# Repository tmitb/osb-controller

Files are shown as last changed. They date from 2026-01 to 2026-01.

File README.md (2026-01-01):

# OSB Controller

This branch contains a project that includes both hardware and software stacks for a gamepad based on the ESP32‑C3. The project was started out of a personal need for a button pad to control OBS while playing games.

The information and experience gathered from this project will be used for the following potential projects:
- Racing sim wheel
- Racing sim button stack
- Flight‑sim controls

## Hardware
I chose the ESP32‑C3 because I have a lot of them lying around. The goal is to build a fully functional Bluetooth gamepad.

### Design considerations
- The development board I have is the ESP32‑C3 Super Mini. Due to its size it only has 11 GPIO pins that can be used safely after removing two buttons (the Boot button and the LED). Eleven buttons will be more than enough for the initial version that controls OBS.
- The shell will be 3D‑printed.
- Mechanical keyboard switches will be used for the buttons.

### BOM
- [x] ESP32‑C3 Super Mini
- [x] Shell
- [x] Switches
- [x] Keycaps

#### ESP32‑C3 Gamepad
Although it is possible to have 11 buttons, I opted to use only 10 of them because that looks better. It may be possible to add more buttons, as there are additional GPIOs (GPIO8 and GPIO9) that are wired for other functions – the built‑in LED and the BOOT pin, respectively.

Ultimately, I have used GPIO0‑7, 10, and 20 for buttons 1‑10.

#### 3D prints
STL files can be found in the `hardware/3d-models` directory.

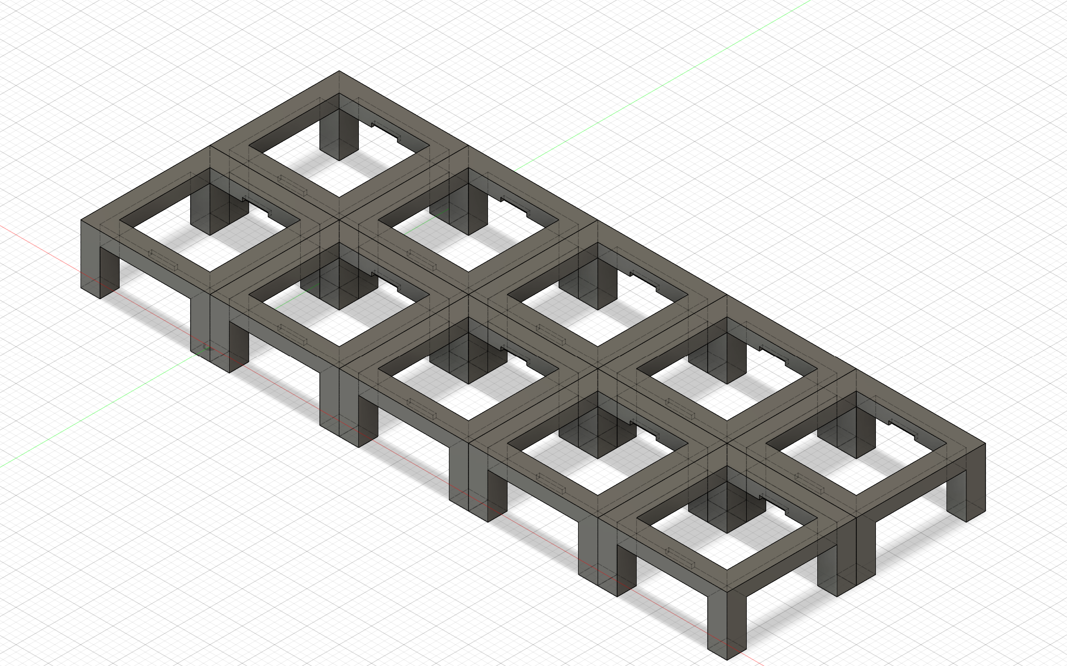
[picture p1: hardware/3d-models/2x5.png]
Button Grid

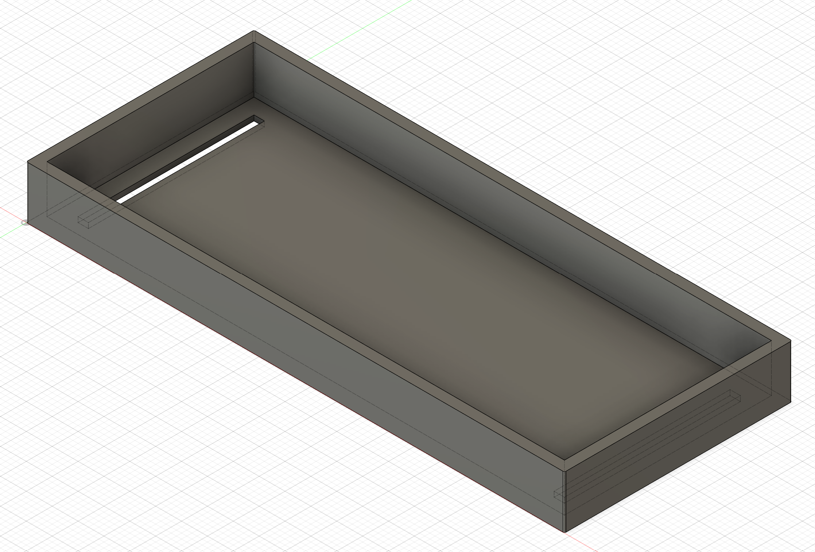
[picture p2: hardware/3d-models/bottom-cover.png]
Bottom Cover

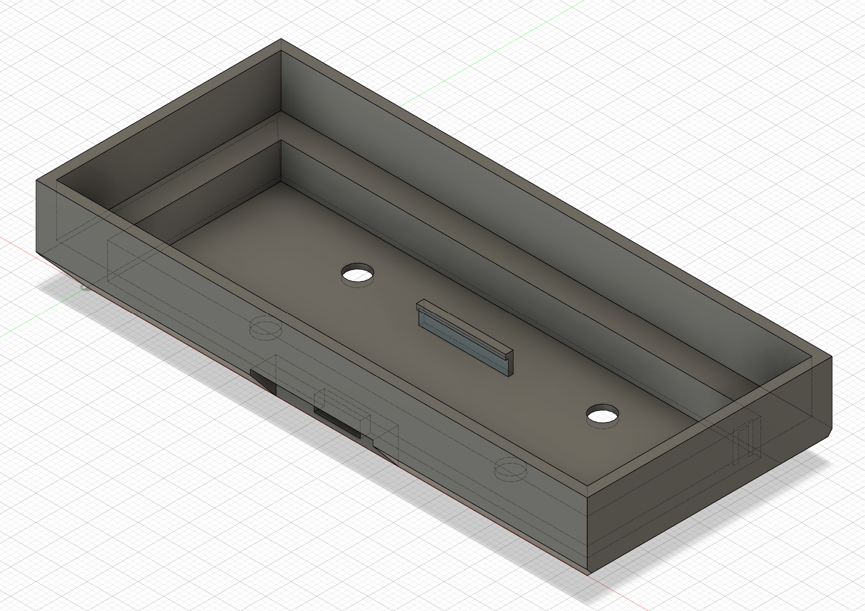
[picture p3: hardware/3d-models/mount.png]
Mount

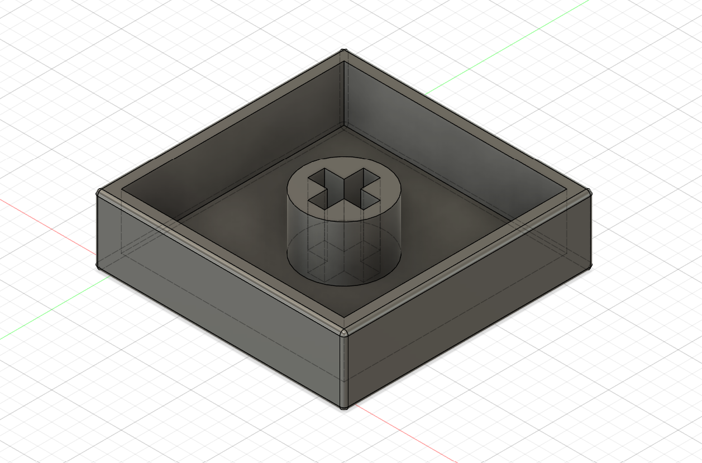
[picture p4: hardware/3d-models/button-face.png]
Button face


#### Assembly
I aimed to design a shell that is easy to assemble and disassemble because prototype devices typically require many iterations.

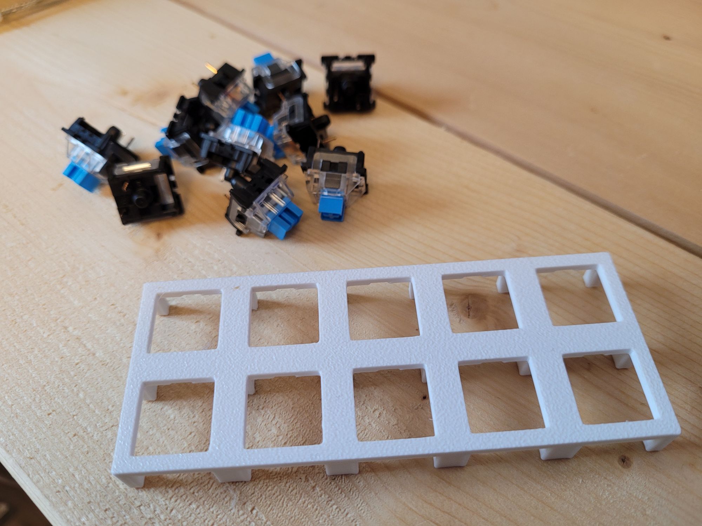
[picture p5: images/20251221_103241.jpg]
Base and switches

The first step was to create a grid that the switches could easily snap into. The dimensions are based on Cherry‑style switches with notches on the top and bottom sides to ensure a tight fit.

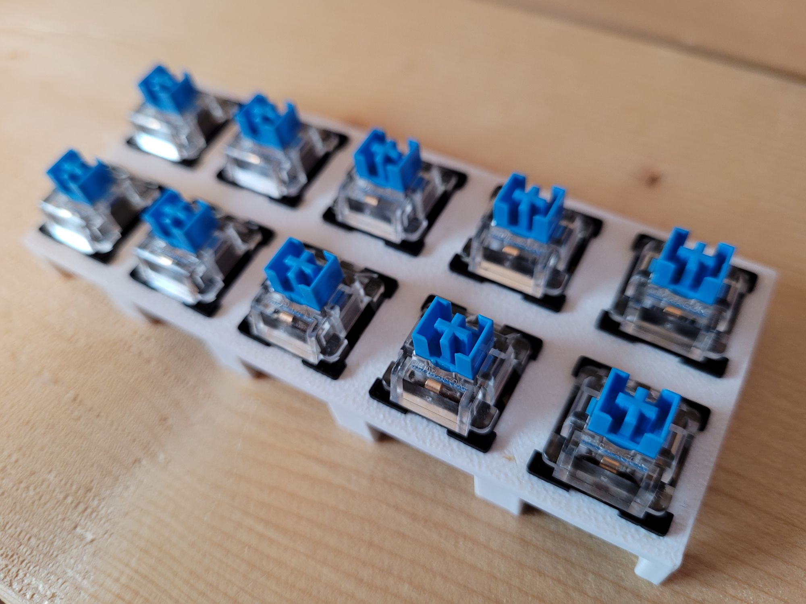
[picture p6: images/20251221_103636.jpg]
Switches in the grid

This is how it looks after all the buttons are installed.
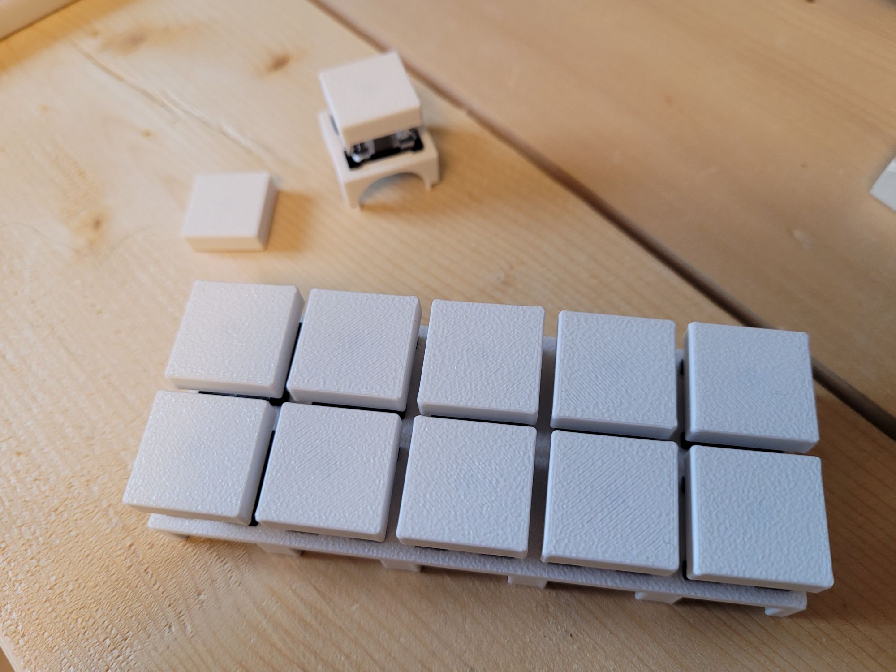
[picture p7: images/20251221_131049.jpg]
Button caps installed

The button caps are flat; this is not a keyboard, so the slight concave shape common on keyboards is unnecessary.

I found that the switches have noticeable slack when I wiggle them. They were likely low‑quality units purchased cheaply from AliExpress – I don’t remember the exact model. They look aligned enough for me, but others may find this unacceptable.

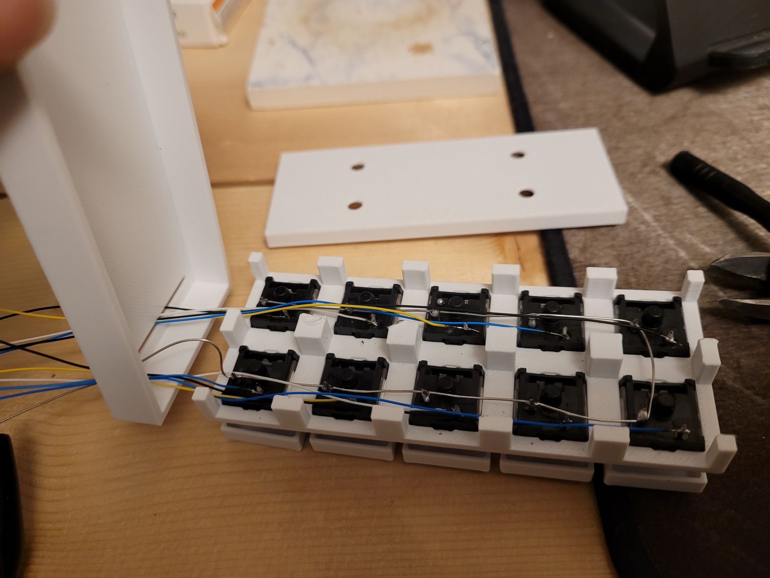
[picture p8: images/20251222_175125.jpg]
Buttons soldered


For Rev 1 I decided to solder all the buttons. Eventually I would like to design a PCB for it, but that is a future task.
If you look closely, there are two slots on the bottom cover for routing wires. Originally I added snap‑fit tabs on the mount to hold pieces together, but they were not strong enough for repeated assembly/disassembly cycles. After about ten failed prototypes I gave up on the idea of having tabs to hold the pieces together, which left me with two slots design instead of necessary single slot.

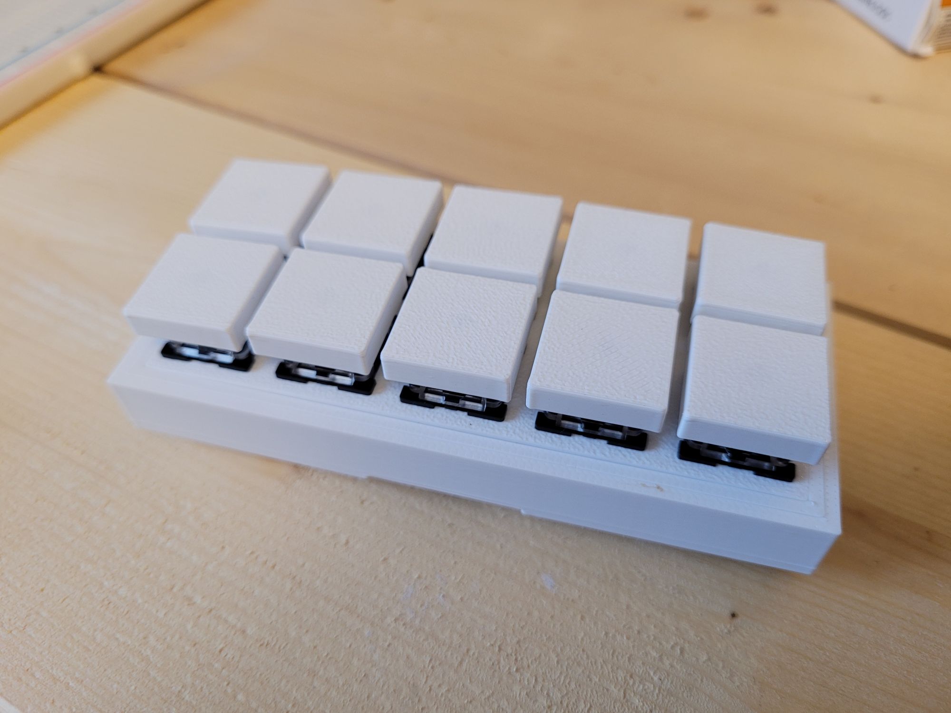
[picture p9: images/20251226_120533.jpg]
Fully Assembled

It is very easy to assemble this device: place the grid into the cover, then insert the whole cover‑plus‑grid assembly into the mount. The natural layer lines of the 3D prints create enough friction to hold the assembly tightly. One unexpected outcome is that disassembly can be quite hard because the friction is high; I could pry it apart with sufficient force, but I was not inclined to print another shell after more than ten failed prototypes to fix a minor inconvinence.

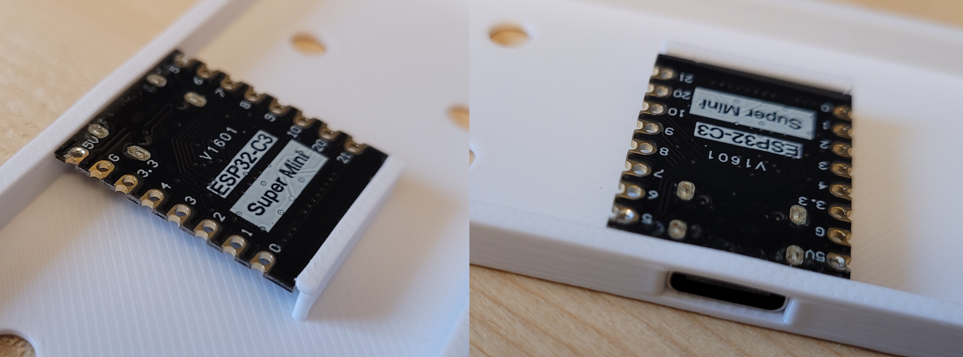
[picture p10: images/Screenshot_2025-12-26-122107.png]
ESP32‑C3 mounted

I was unable to photograph how the ESP32‑C3 Super Mini is mounted, so I used a photo of a failed prototype instead – the mounting concept is identical. When looking at the module, the USB port protrudes slightly from the PCB. Using this, I created a slot in the side of the mount to push the port into, and at an exact distance I added a wall with a slight tab at the top. Because PLA prints have enough flex, I could jam the module in with a bit of force. It fits tightly without issues so far, though stress over time may become a concern.

#### Arduino code
A single sketch for the ESP32‑C3 can be found [here](hardware/ble-gamepad/ble-gamepad.ino). The code is a slightly modified version of an example from the [NimBLE‑Arduino](https://github.com/h2zero/NimBLE-Arduino) library.

#### Simple tests
Even without a full software stack to use it as an OBS controller, this works as a perfectly good game controller. First, pair it via Bluetooth.

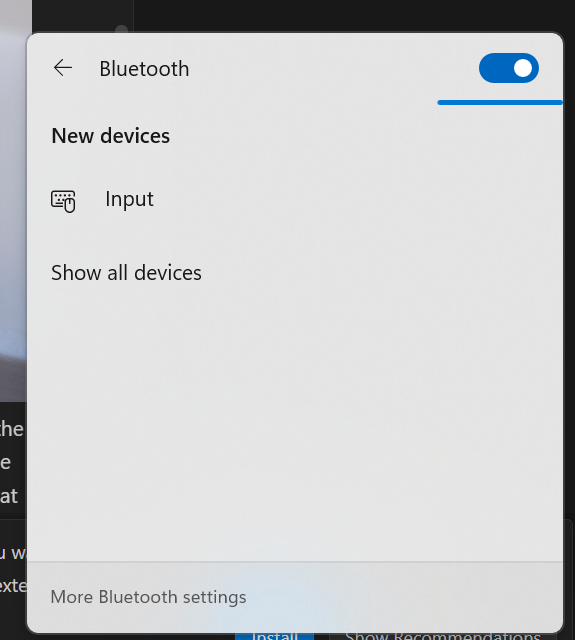
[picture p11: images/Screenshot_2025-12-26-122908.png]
Before Pair

Before pairing
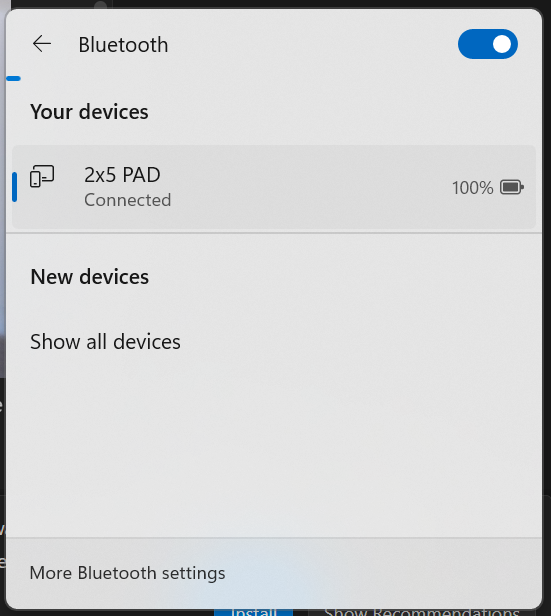
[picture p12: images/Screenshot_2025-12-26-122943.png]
After Pair

After pairing

The device appears as an input device, showing the name `2x5 PAD`. This name can be changed in the Arduino code.

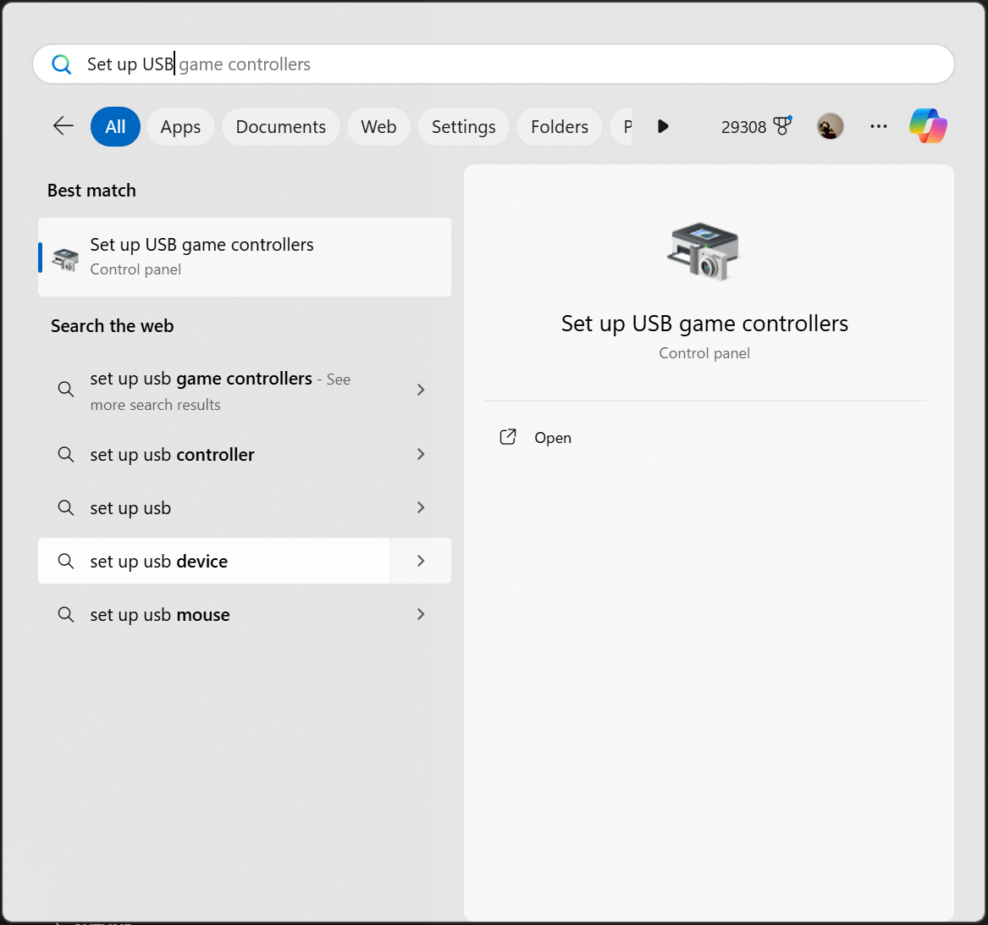
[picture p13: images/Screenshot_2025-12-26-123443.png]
Game Controller App

To test the gamepad, open the built‑in Windows “Game Controllers” app (search for it). The list shows all connected controllers. My own fight stick appears first; ignore that entry. The ESP32‑based controller shows up as `8 Axis 16 Button Device with Hat Switch`. This name seems random and I am not sure where it originates, but it does not affect functionality. It can be changed via the Registry Editor by finding all occurrences and replacing them.

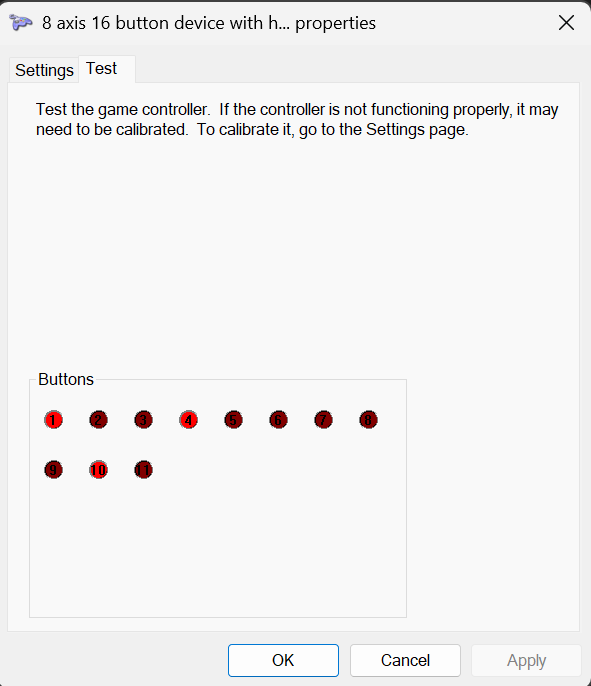
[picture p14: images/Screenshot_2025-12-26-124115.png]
Test

In the test dialog, the second tab displays the status of each control. Press the switches to see their corresponding circles light up. As mentioned earlier, the software reports 11 buttons to take advantage of all available pins, but only ten are wired so the product looks tidier. I plan to reuse the Arduino code in the future to support all 11 buttons.

## Software
There are several goals, requirements, and highlights for this section:
- Controlling OBS using a gamepad
- The software will be built mostly using AI code agents (Vibe Coding)
  - Most of the code was built by AI using gpt-oss-120b local model.
  - It took about 12 hours of total time to build it. Of 12 hours, about 4 hours of work was done by me for both manual coding and interactions with AI.
  - about 4 hours was spent on the python prototype which failed miserably due to insufficient supporst for the gamepads that are not XInput compatible.
 
At this point, the software is functional to meet my own requeirments. You can see the details of the software in [software/README.md](./software/README.md) file.

### Tech notes
The current software section has the code using C# and .Net 8. This was my first choice for this project when it was started, but AI guided me to python prototype initially. As mentioned above, that experiment failed for the said reason, and eventually I decided to come back to this.

I have done some testing using another game controller that is not my own to understand how it must be coded. I was successful at changing the OBS scene using a button press. One thing I have noticed that the Windows SDK exposes anything it does not know(put it differently, something that is not XInput compatible) as `RawGameController`.

Another thing that I spent a lot of time on was the bug that was caused by how `RawGameController.RawGameControllers` behaves. It is actually well documented but AI does not know how it supposed to work and caused a massive headache for me. This Read-only collection is asynchronously updated by the Windows itself meaning that accessing it for the first time usually does not have information ready. I ended up create a loop to check it every 1 second for up to ten seconds to wait for it to be populated. A crude solution because there are other smarter way to do it, but I am happy with what I have because it works for me.

### TO-DOs
I want to add some unit tests and integration tests, though I do not want to deal with mocking OBS and Physical gamepad for the automated tests. I may or may not get to them.

## License
Please check the [LICENSE](./LICNESE) file for more details. Also check [THIRD_PARTY_NOTICES](./THIRD_PARTY_NOTICES) for the license related information regarding libraries that are used.

## Contributions
All contributions are welcome. Just follow the general coding style you can find in this project, then create a Pull Request. I will review them and decide what to do. If you do not want to waste time making changes then getting rejected, create an issue first to discuss potential the changes with me before commiting your time.

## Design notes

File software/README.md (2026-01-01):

# BLE‑OBS Controller

## Overview

This repository contains the source code for a **BLE gamepad → OBS** controller. A small ESP32‑C3 board runs custom firmware that emulates a Bluetooth Low Energy (BLE) gamepad. The companion desktop application, written in C#, reads the BLE gamepad input on Windows and forwards button presses to **OBS Studio** over its WebSocket API.

The project is focusing on the software portion of the entire solution.

* `software/` – a .NET console application located in the **ObsController** solution. It handles:
  * Loading a JSON mapping file (`mapping.json`).
  * Connecting to OBS via WebSocket.
  * Listening for button state changes from the BLE gamepad (through Windows.Gaming.Input).
  * Executing the configured OBS actions (start/stop streaming, toggle recording, switch scenes, …).

The README below explains how to build, configure and run the software on a Windows machine.

---

## Prerequisites

* **Windows 10/11** – the controller uses `Windows.Gaming.Input.RawGameController` which is only available on Windows.
* **.NET 8 SDK** – required to build the C# project (`dotnet build`).
* **OBS Studio** with the *WebSocket* plugin enabled (default in OBS 28+). Make sure you note the WebSocket port and password.
* (Optional) **ESP32‑C3 board** flashed with `hardware/ble-gamepad/ble-gamepad.ino` if you want to use the hardware version.

---

## Getting Started

### 1. Clone the repository

```powershell
git clone https://github.com/tmitb/obs-controller.git
cd ble-obs-controller
```

### 2. Build the .NET application

```powershell
dotnet restore                # restores NuGet packages
dotnet build -c Release       # builds ObsController.exe in `bin/Release/net8.0-windows`
```

If you prefer a single‑file executable you can also run:

```powershell
dotnet publish -c Release /p:PublishSingleFile=true /p:SelfContained=true
```

The resulting `ObsController.exe` will be placed in the publish folder.

---

## Configuration (`mapping.json`)

`mapping.json` defines how button indices map to OBS actions and also stores the connection details for OBS.

```json
{
  "deviceIdentifier": "<NonRoamableId of your BLE gamepad>",
  "host": "localhost",
  "port": 4455,
  "password": "your‑obs‑websocket‑password",
  "buttonMap": {
    "0": { "action": "StartStreaming" },
    "1": { "action": "StopStreaming" },
    "2": { "action": "ToggleRecording" },
    "3": { "action": "SwitchScene", "parameter": "Game" }
  }
}
```

* **`deviceIdentifier`** – the id reported by Windows for the BLE gamepad. When you first run the app it prints a list of detected controllers; copy the `Id` value that matches your hardware. If not sure, try each one of them until you find the one you want.
* **password** - is not required if OBS is setup to work without authentication.
* **Button map keys** are *zero‑based indices* as defined by the controller firmware. Windows test app is using 1 based button scheme so you may see the numbers differ by 1.
* Supported actions (as of today) are:
  * `StartStreaming`
  * `StopStreaming`
  * `ToggleRecording`
  * `SwitchScene` – requires a `parameter` containing the target scene name.
* New OBS action can be implemented based on the official document [found here](https://github.com/obsproject/obs-websocket/blob/master/docs/generated/protocol.md#requests)
  * There are two places that must be edited. One switch statement in `Programs.cs` file and a new function in `ObsBridge.cs` file must be added to support a new function.
  * No plan to add more unless I need them. Contribution are welcome.

You can extend the JSON schema to add more actions by editing `ObsController/Models/Mapping.cs` and implementing the corresponding case in `Program.HandleStateChanges`.

---

## Running the controller

```powershell
# From wherever ObsController.exe lives and use mapping
.\ObsController.exe
# or override some settings in mappings.
.\ObsController.exe 
    --host localhost \
    --port 4455 \
    --password "mySecret"
```

All three command‑line options are *optional* and I only really tested the application using mapping.json file. – if omitted the values from `mapping.json` are used. The program will:

1. Load `mapping.json`.
2. Connect to OBS via WebSocket.
3. Enumerate available gamepads and print their IDs (helpful for setting `deviceIdentifier`).
4. Listen for button presses and forward the configured actions to OBS.
5. Keep running until you press **Ctrl +C**.

---

## Building a Windows executable (optional)

If you want a portable single‑file binary you can use `dotnet publish` as shown earlier.

---

## Contributing

Please follow the repository guidelines in `AGENTS.md`:

* Use **4‑space indentation** and PEP 8 / C# coding conventions.
* Keep commit messages concise (≤50 characters) with an optional body.
* Update `mapping.json` or the code when adding new OBS actions.
* Do not commit real OBS passwords – use environment variables (`OBS_PASSWORD`) or the command‑line overrides.

Open a PR that references an existing issue, includes a clear description of the changes and any new dependencies.

---

## License

This project is licensed under the **MIT License** – see `LICENSE` for details.

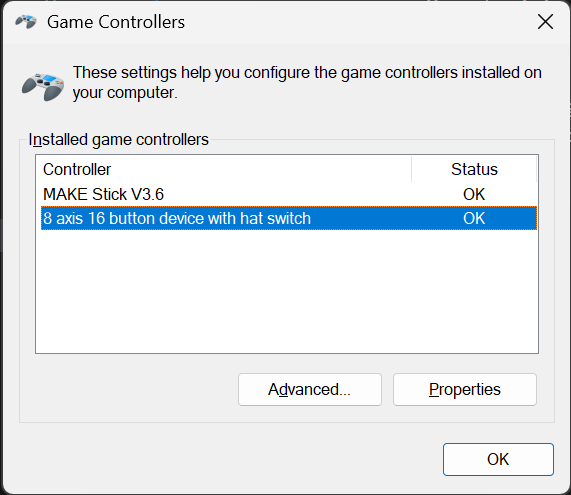
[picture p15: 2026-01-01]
images/Screenshot_2025-12-26-123635.png

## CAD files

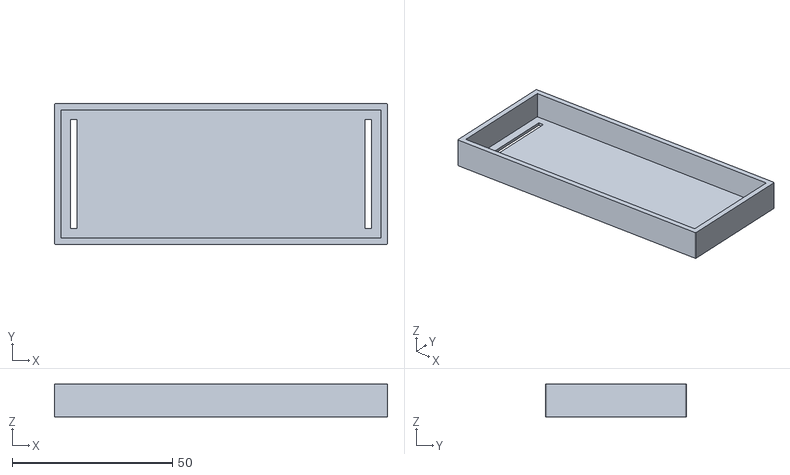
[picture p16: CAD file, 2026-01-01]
hardware/3d-models/bottom-cover.stl
104.0 x 44.0 x 10.2

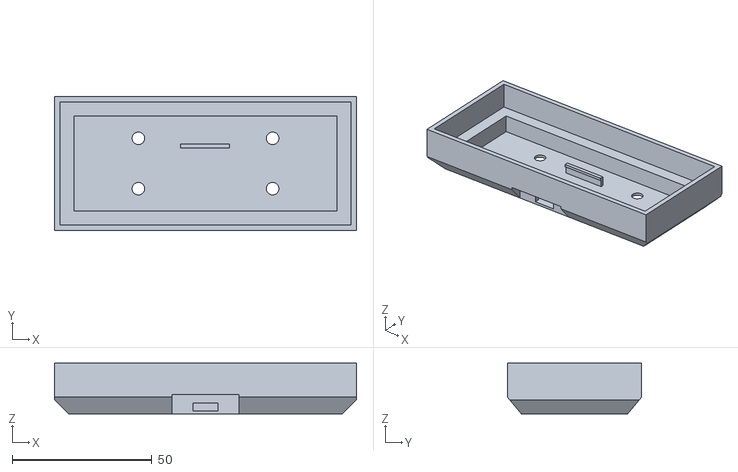
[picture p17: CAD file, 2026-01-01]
hardware/3d-models/mount.stl
108.0 x 48.0 x 18.2

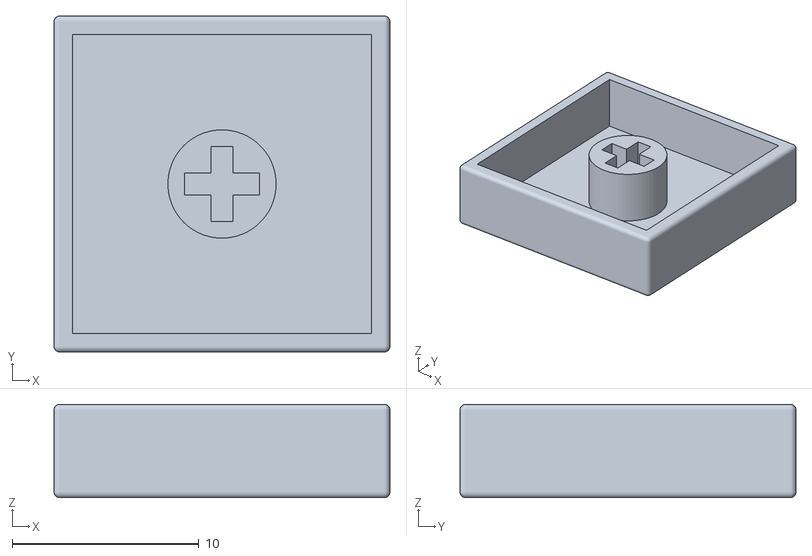
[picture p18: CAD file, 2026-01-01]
hardware/3d-models/button-face.stl
18.0 x 18.0 x 5.00

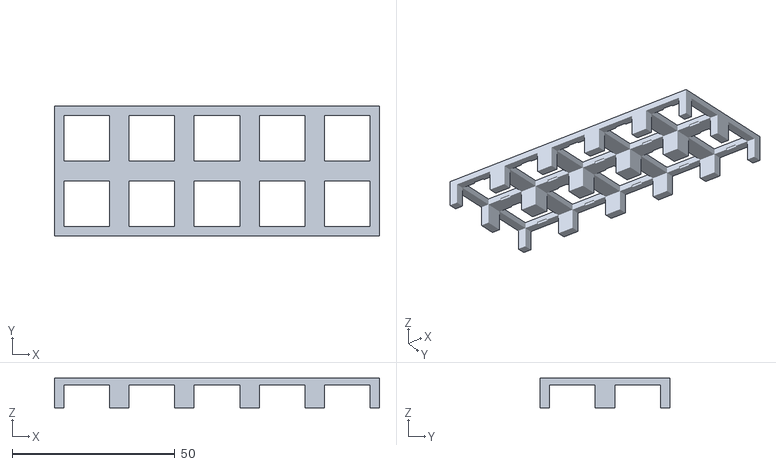
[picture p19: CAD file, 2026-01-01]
hardware/3d-models/2x5.stl
100.0 x 40.0 x 9.10

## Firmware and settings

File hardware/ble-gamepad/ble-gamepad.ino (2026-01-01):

/*
 * A simple sketch that maps a single pin on the ESP32 to a single button on the controller
 */

#include <Arduino.h>
#include <GamepadDevice.h>
#include <BleCompositeHID.h>

BleCompositeHID compositeHID("2x5 PAD");
GamepadDevice* gamepad;
short enabledButtons[] = { 0, 1, 2, 3, 4, 5, 6, 7, 10, 20, 21 };
int previousButtonStates[] = { HIGH, HIGH, HIGH, HIGH, HIGH, HIGH, HIGH, HIGH, HIGH, HIGH, HIGH };

void setup() {
  // Start the serial connection. It will be probably removed once the code is stabilized
  Serial.begin(115200);

  // Setup buttons
  Serial.println("Setup pins");
  for (int ctr = 0; ctr < sizeof(enabledButtons) / sizeof(enabledButtons[0]); ctr++) {
    pinMode(enabledButtons[ctr], INPUT_PULLUP);
  }

  // Start game pad
  Serial.println("Setup the game pad");
  GamepadConfiguration config;
  config.setButtonCount(sizeof(enabledButtons) / sizeof(enabledButtons[0]));
  config.setHatSwitchCount(0);
  config.setIncludeXAxis(false);
  config.setIncludeYAxis(false);
  config.setIncludeZAxis(false);
  config.setIncludeRxAxis(false);
  config.setIncludeRyAxis(false);
  config.setIncludeRzAxis(false);
  config.setIncludeSlider1(false);
  config.setIncludeSlider2(false);
  config.setAutoReport(true);
  config.setAutoDefer(true);

  gamepad = new GamepadDevice(config);

  compositeHID.addDevice(gamepad);
  compositeHID.begin();
}

void loop() {
  if (compositeHID.isConnected()) {
    for (int ctr = 0; ctr < sizeof(enabledButtons) / sizeof(enabledButtons[0]); ctr++) {
      int state = digitalRead(enabledButtons[ctr]);
      if (state != previousButtonStates[ctr]) {
        if (previousButtonStates[ctr] == LOW) {
          gamepad->release(ctr + 1);
          Serial.print(enabledButtons[ctr]);
          Serial.println(" Pressed");
        } else {
          gamepad->press(ctr + 1);
          Serial.print(enabledButtons[ctr]);
          Serial.println(" Released");
        }
        previousButtonStates[ctr] = state;
      }

      // Update all buttons at once.
      compositeHID.sendDeferredReports();
    }
  }
}
